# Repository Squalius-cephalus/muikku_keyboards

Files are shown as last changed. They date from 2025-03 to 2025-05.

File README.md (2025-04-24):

# Muikku58

Muikku58 is a RP2040 based 56-key column staggered split keyboard, that uses Redragon low profile switches. Design is inspired from REVIUNG41 and Corne keyboards.

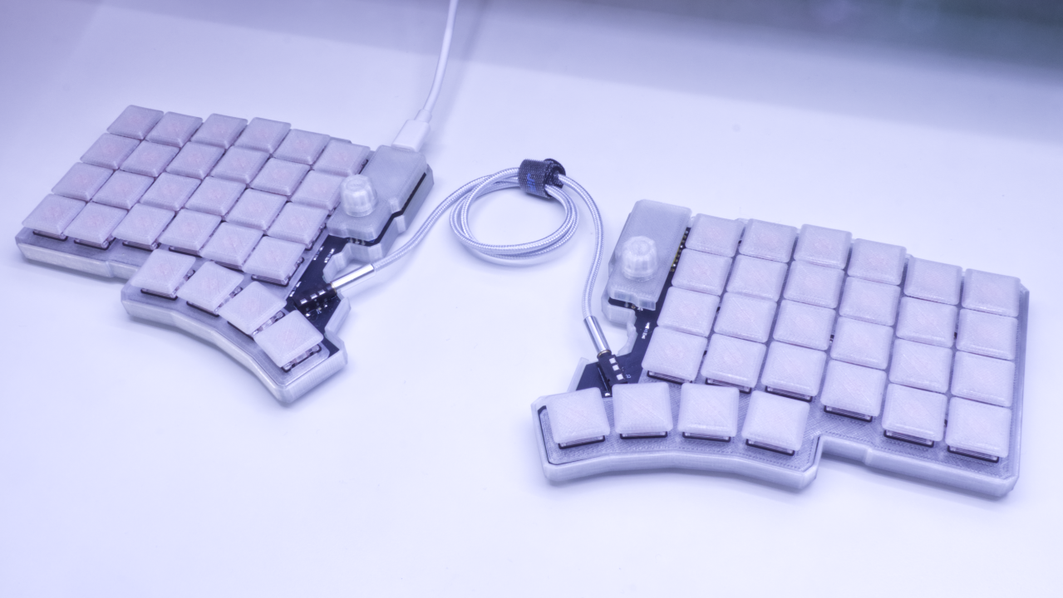
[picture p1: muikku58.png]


## Bill of materials

 - 2 x Muikku58 PCB
 - 2 x RP2040 Zero
 - 2 x 3D printed case
 - 2 x 3D printed plate
 - 2 x 3D printed MCU cover
 - 2 x EC11 Rotary encoders
 - 2  x TRRS connector(PJ320D)
 - 56 x Redragon low profile switches
 - 56 x Low profile MX compatible keycaps
 - 22 x M2 4mm bolt
 - 22 x M2 brass inserts(M2xL3xOD3.2)
 - 12 x Rubber feet

# Muikku18

Muikku18 is a 16-key macro pad, that also uses Redragon low profile switches. 

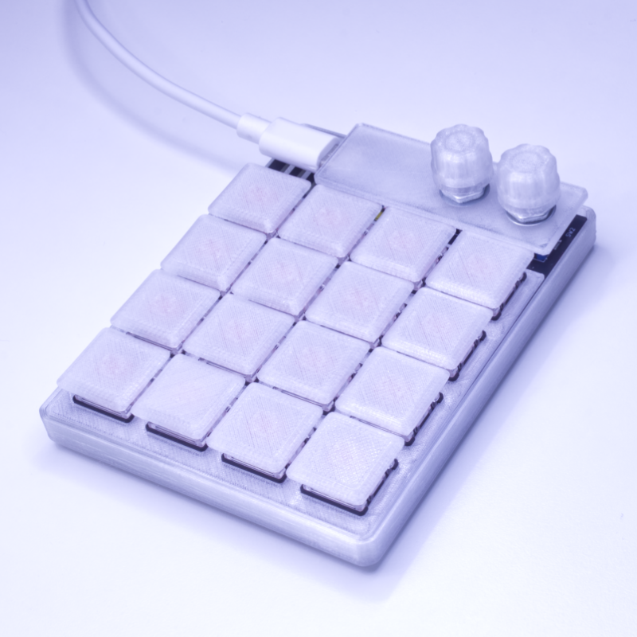
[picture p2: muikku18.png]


## Bill of materials

 - 1 x Muikku18 PCB
 - 1 x RP2040 Zero
 - 1 x 3D printed case
 - 1 x 3D printed plate
 - 1 x 3D printed MCU cover
 - 2 x EC11 Rotary encoders
 - 16 x Redragon low profile switches
 - 16 x Low profile MX compatible keycaps
 - 5 x M2 4mm bolt
 - 5 x M2 brass inserts(M2xL3xOD3.2)
 - 6 x Rubber feet

Both PCB design uses footprints from [ScottoKeebs](https://github.com/joe-scotto/scottokeebs/tree/main/Extras/ScottoKicad "ScottoKeebs") and [kbd library.](https://github.com/foostan/kbd "kbd library.")

Redragon switch footprint is from [keyboard-labs repository.](https://github.com/rgoulter/keyboard-labs "keyboard-labs")

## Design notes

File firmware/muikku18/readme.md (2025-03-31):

# Muikku18

Muikku18

Muikku18 is a RP2040 Zero based 18-key macro pad that uses Redragon low profile switches.

* Keyboard Maintainer: [Squalius-cephalus](https://github.com/Squalius-cephalus)
* Hardware Supported: Muikku58 PCB
* Hardware Availability: https://github.com/Squalius-cephalus/muikku_keyboards

Make example for this keyboard (after setting up your vial build environment):

    make muikku_keyboard/muikku58:vial

## Bootloader

Enter the bootloader in 2 ways:

* **Physical boot button**: Hold BOOT button down and connect MCU to the PC
* **Keycode in layout**: Press the key mapped to `QK_BOOT` if it is available

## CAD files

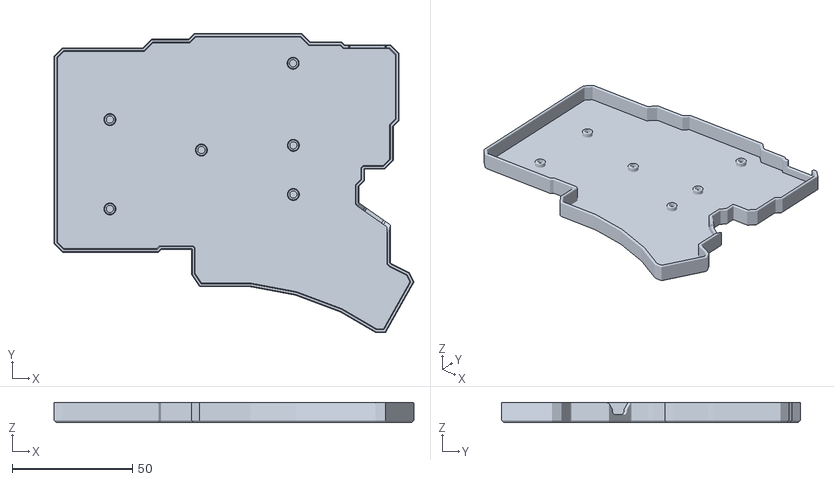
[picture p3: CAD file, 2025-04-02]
stl/muikku58_case.stl
149.5 x 124.3 x 8.50

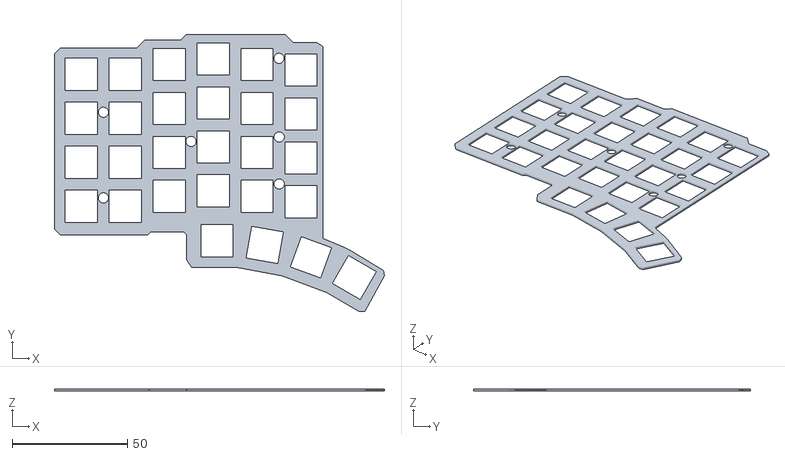
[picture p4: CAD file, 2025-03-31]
stl/muikku58_plate.stl
143.1 x 120.2 x 1.00

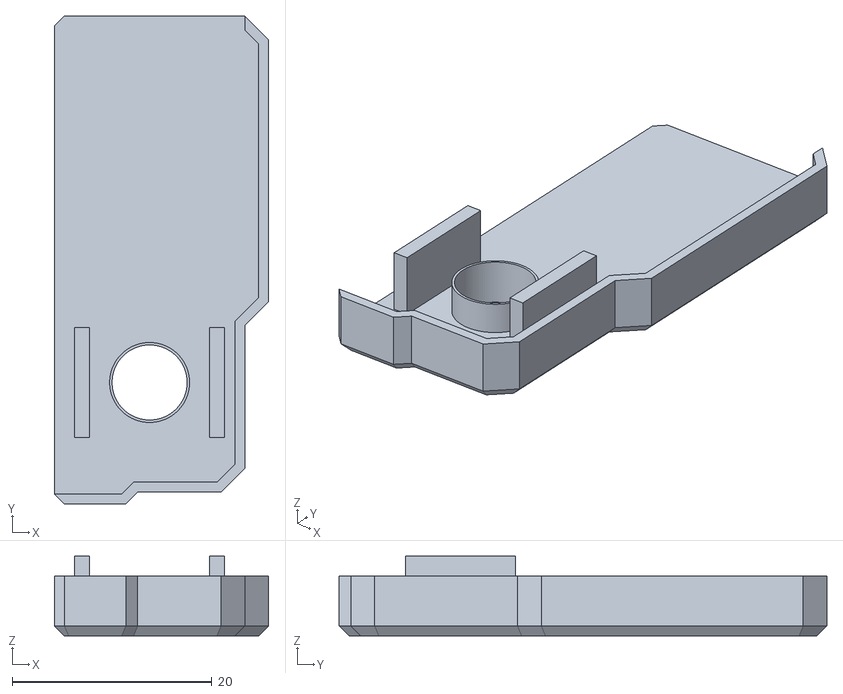
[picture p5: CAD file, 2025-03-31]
stl/muikku58_mcu_cover.stl
21.4 x 48.8 x 8.00

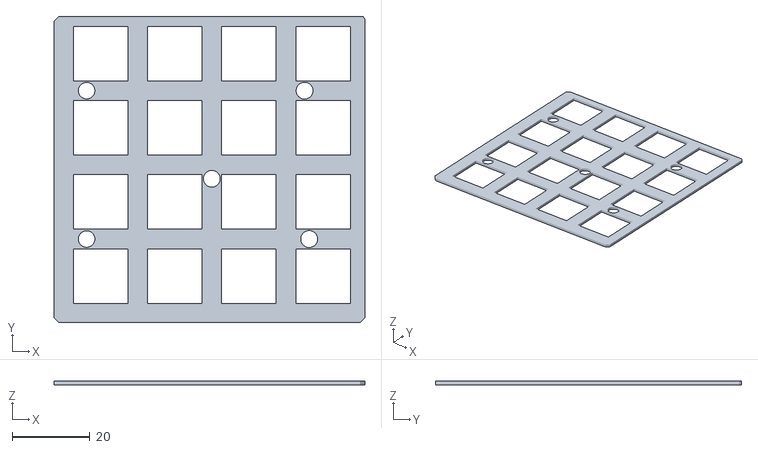
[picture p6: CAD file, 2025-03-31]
stl/muikku18_plate.stl
79.8 x 78.6 x 1

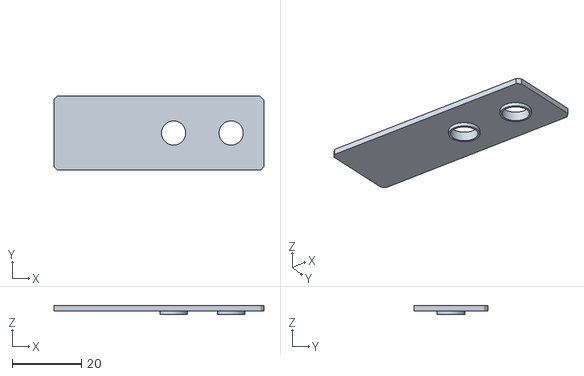
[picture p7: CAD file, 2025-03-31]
stl/muikku18_mcu_cover.stl
60.8 x 21.4 x 2.50

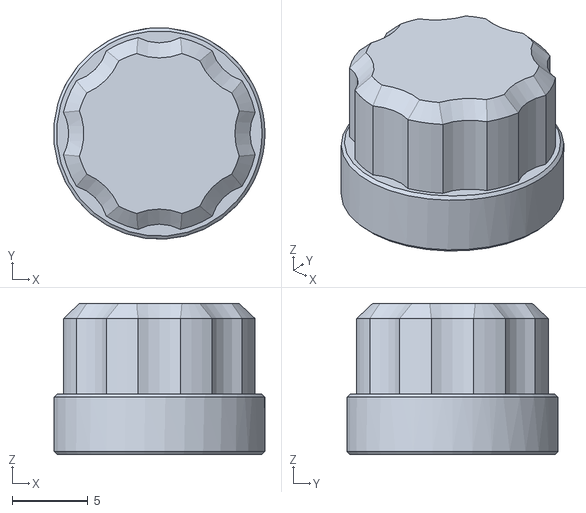
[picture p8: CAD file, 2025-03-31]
stl/knob.stl
14.0 x 14.0 x 10.0

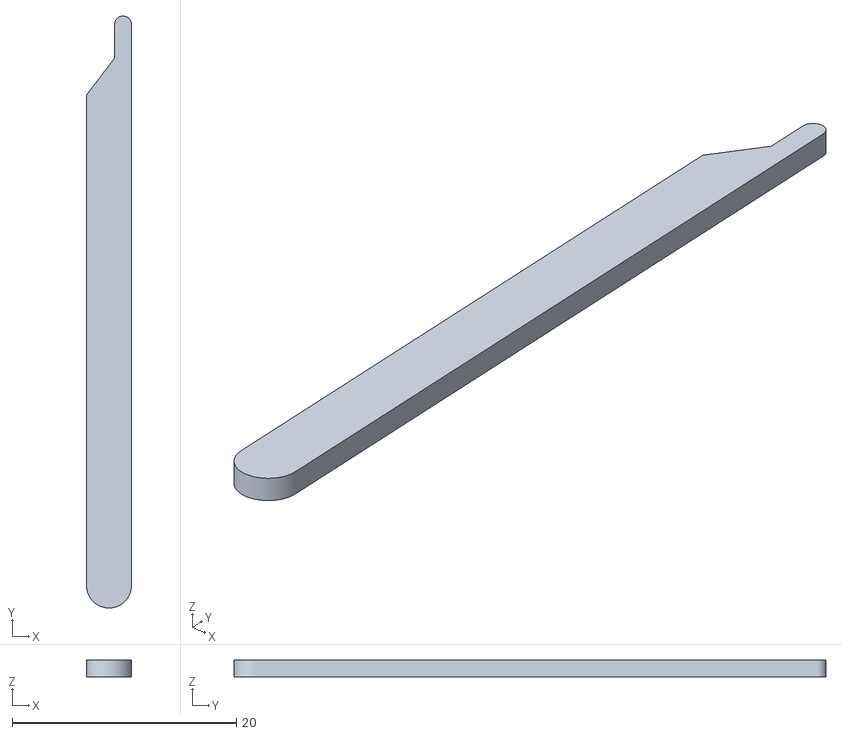
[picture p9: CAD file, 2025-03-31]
stl/mcu_tool.stl
4.00 x 52.8 x 1.50

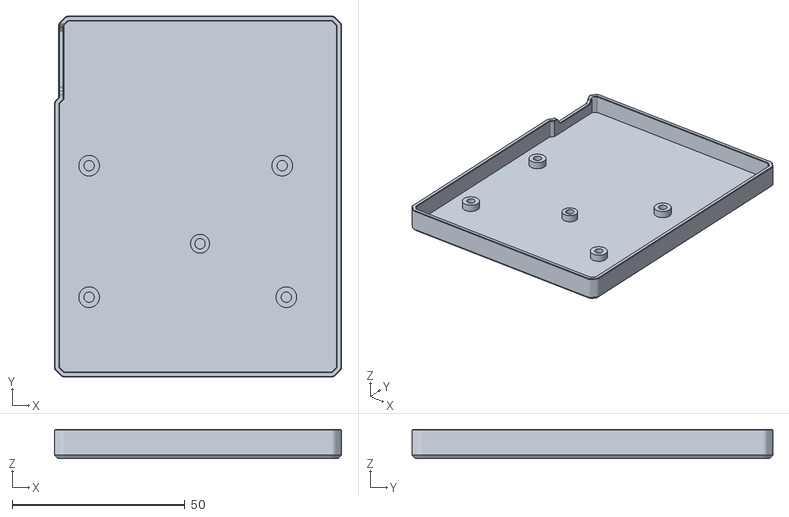
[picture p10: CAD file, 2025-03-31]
stl/muikku18_case.stl
83.2 x 104.6 x 8.50

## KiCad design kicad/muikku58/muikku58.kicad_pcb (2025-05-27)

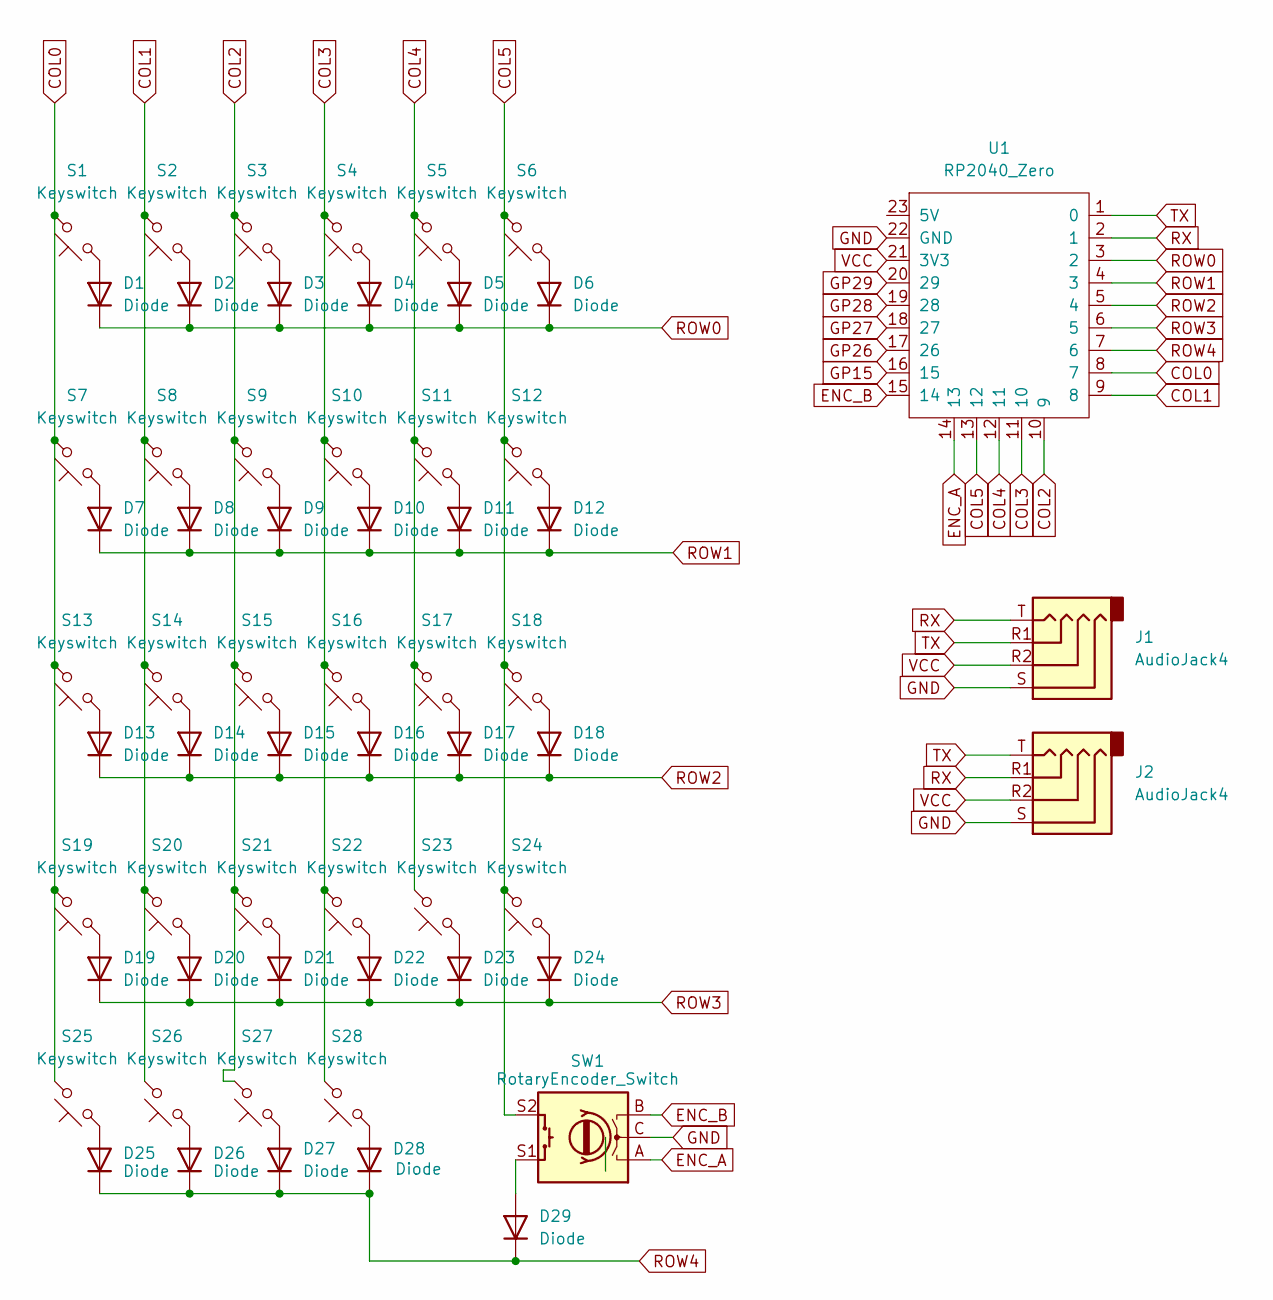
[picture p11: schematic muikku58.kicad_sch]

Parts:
D1, D2, D3, D4, D5, D6, D7, D8, D9, D10, D11, D12, D13, D14, D15, D16, D17, D18, D19, D20, D21, D22, D23, D24, D25, D26, D27, D28, D29: Diode; D3_TH_SMD_v2
J1, J2: AudioJack4; Jack_3.5mm_PJ320D_Horizontal
S1, S2, S3, S4, S5, S6, S7, S8, S9, S10, S11, S12, S13, S14, S15, S16, S17, S18, S19, S20, S21, S22, S23, S24, S25, S26, S27, S28: Keyswitch; SW_Redragon_LowProfile_PCB_1.00u_REV
SW1: RotaryEncoder_Switch; RotaryEncoder_Alps_EC11E-Switch_Vertical_H20mm
U1: RP2040_Zero

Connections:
COL0: S1.2, S7.2, S13.2, S19.2, S25.2, U1.8 (7)
COL1: S2.2, S8.2, S14.2, S20.2, S26.2, U1.9 (8)
COL2: S3.2, S9.2, S15.2, S21.2, S27.2, U1.10 (9)
COL3: S4.2, S10.2, S16.2, S22.2, S28.2, U1.11 (10)
COL4: S5.2, S11.2, S17.2, S23.2, U1.12 (11)
COL5: S6.2, S12.2, S18.2, S24.2, SW1.S2, U1.13 (12)
ENC_A: SW1.A, U1.14 (13)
ENC_B: SW1.B, U1.15 (14)
GND: J1.S, J2.S, SW1.C, U1.22 (GND)
GP15: U1.16 (15)
GP26: U1.17 (26)
GP27: U1.18 (27)
GP28: U1.19 (28)
GP29: U1.20 (29)
unnamed: D1.2 (A), S1.1
unnamed: D2.2 (A), S2.1
unnamed: D3.2 (A), S3.1
unnamed: D4.2 (A), S4.1
unnamed: D5.2 (A), S5.1
unnamed: D6.2 (A), S6.1
unnamed: D7.2 (A), S7.1
unnamed: D8.2 (A), S8.1
unnamed: D9.2 (A), S9.1
unnamed: D10.2 (A), S10.1
unnamed: D11.2 (A), S11.1
unnamed: D12.2 (A), S12.1
unnamed: D13.2 (A), S13.1
unnamed: D14.2 (A), S14.1
unnamed: D15.2 (A), S15.1
unnamed: D16.2 (A), S16.1
unnamed: D17.2 (A), S17.1
unnamed: D18.2 (A), S18.1
unnamed: D19.2 (A), S19.1
unnamed: D20.2 (A), S20.1
unnamed: D21.2 (A), S21.1
unnamed: D22.2 (A), S22.1
unnamed: D23.2 (A), S23.1
unnamed: D24.2 (A), S24.1
unnamed: D25.2 (A), S25.1
unnamed: D26.2 (A), S26.1
unnamed: D27.2 (A), S27.1
unnamed: D28.2 (A), S28.1
unnamed: D29.2 (A), SW1.S1
ROW0: D1.1 (K), D2.1 (K), D3.1 (K), D4.1 (K), D5.1 (K), D6.1 (K), U1.3 (2)
ROW1: D7.1 (K), D8.1 (K), D9.1 (K), D10.1 (K), D11.1 (K), D12.1 (K), U1.4 (3)
ROW2: D13.1 (K), D14.1 (K), D15.1 (K), D16.1 (K), D17.1 (K), D18.1 (K), U1.5 (4)
ROW3: D19.1 (K), D20.1 (K), D21.1 (K), D22.1 (K), D23.1 (K), D24.1 (K), U1.6 (5)
ROW4: D25.1 (K), D26.1 (K), D27.1 (K), D28.1 (K), D29.1 (K), U1.7 (6)
RX: J1.T, J2.R1, U1.2 (1)
TX: J1.R1, J2.T, U1.1 (0)
VCC: J1.R2, J2.R2, U1.21 (3V3)

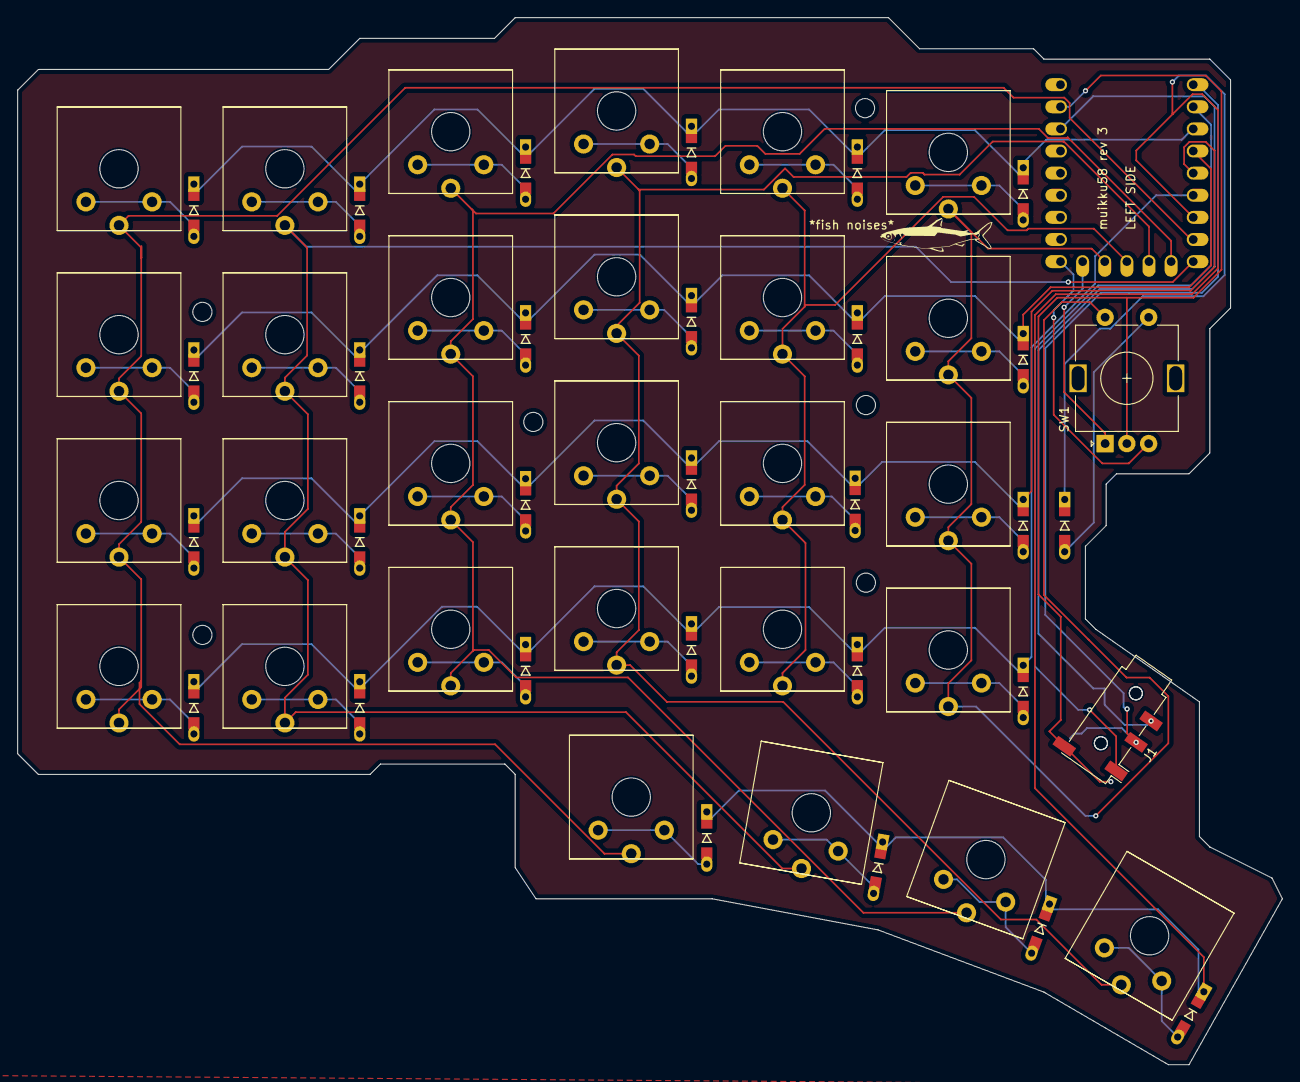
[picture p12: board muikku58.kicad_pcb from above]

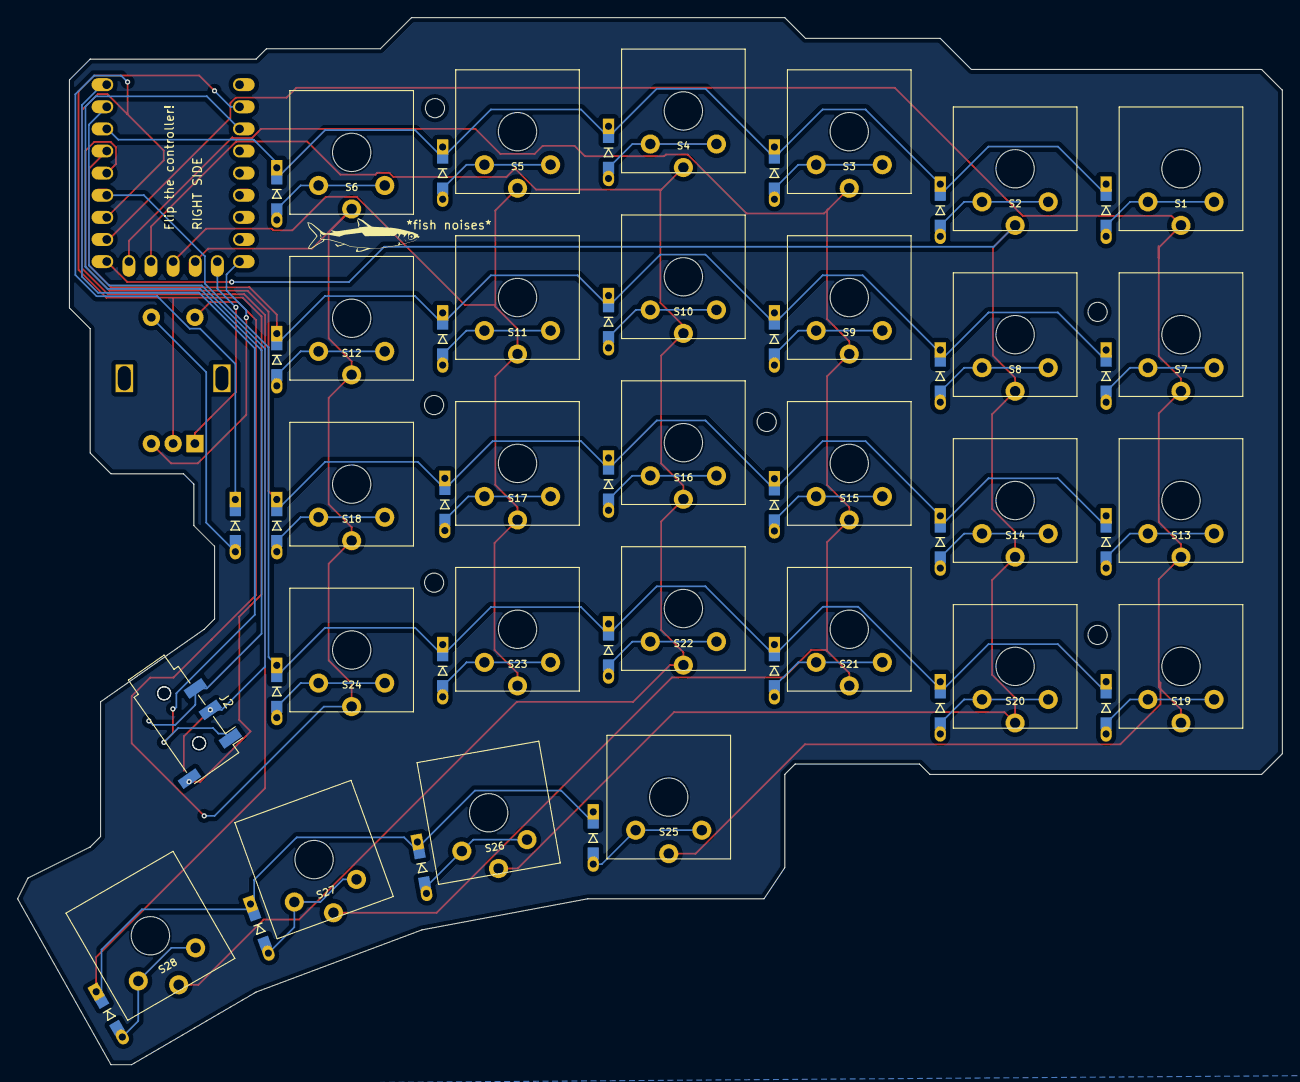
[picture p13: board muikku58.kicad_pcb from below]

Board: 2 copper layers, 145.3 x 120.3 mm, 61 parts (30 on the bottom side), 46 nets.

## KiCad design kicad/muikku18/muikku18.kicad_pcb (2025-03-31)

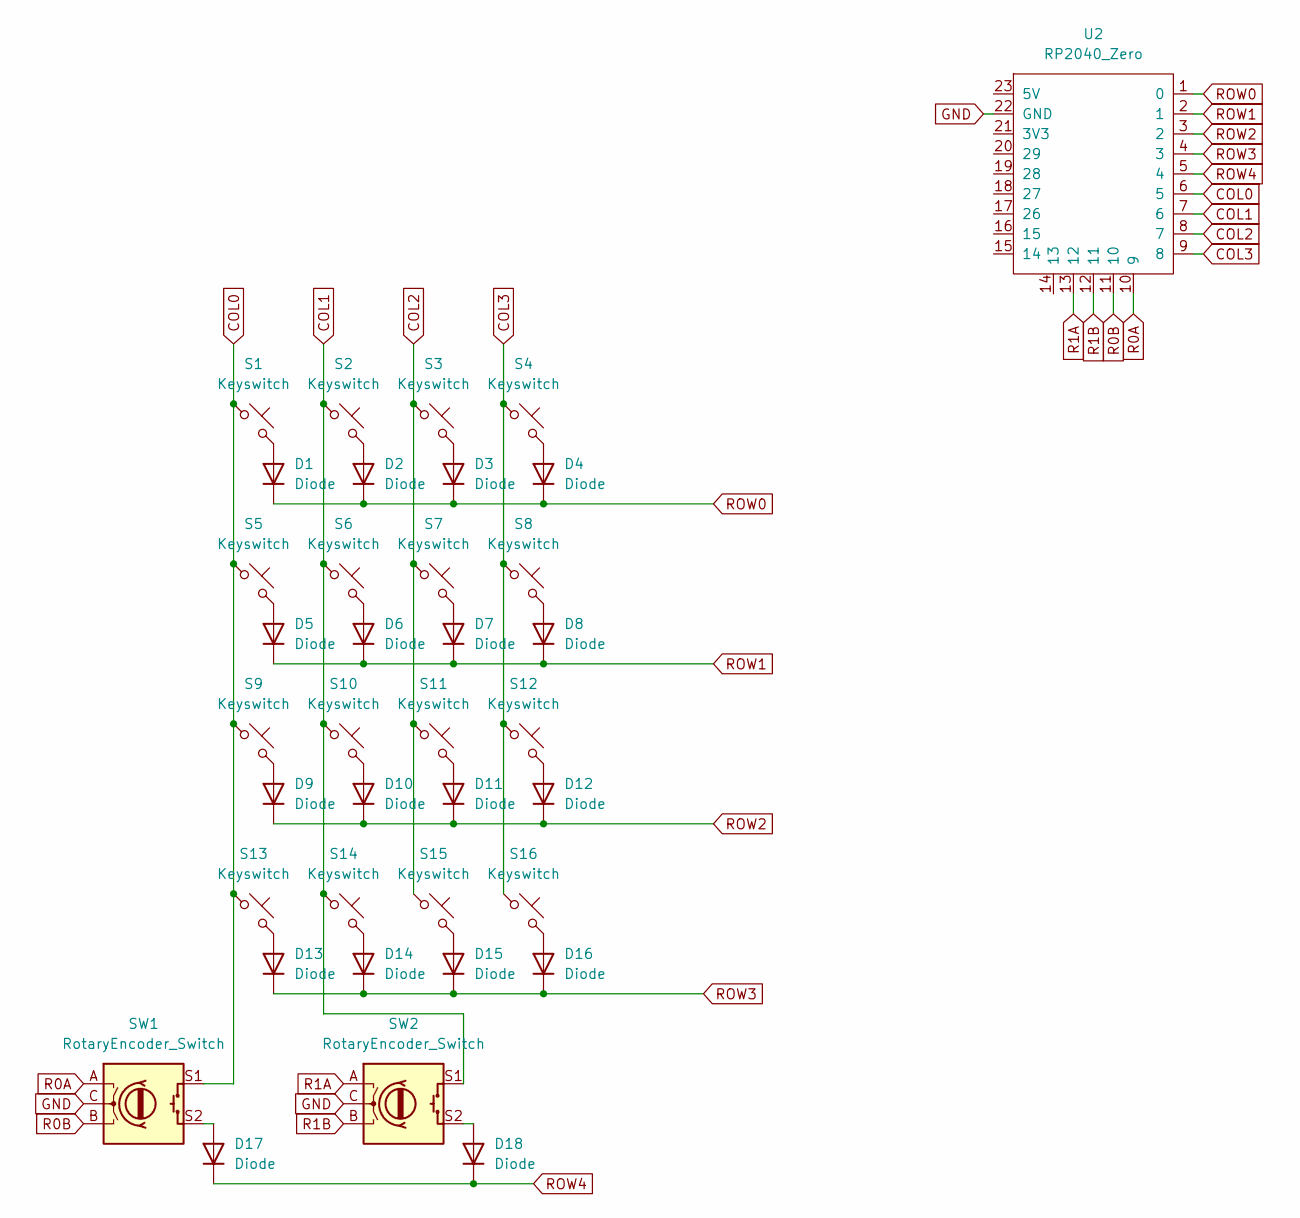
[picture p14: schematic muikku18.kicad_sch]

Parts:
D1, D2, D3, D4, D5, D6, D7, D8, D9, D10, D11, D12, D13, D14, D15, D16, D17, D18: Diode; D3_TH_SMD_v2
S1, S2, S3, S4, S5, S6, S7, S8, S9, S10, S11, S12, S13, S14, S15, S16: Keyswitch; SW_Redragon_LowProfile_PCB_1.00u
SW1, SW2: RotaryEncoder_Switch; RotaryEncoder_Alps_EC11E-Switch_Vertical_H20mm
U2: RP2040_Zero

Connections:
COL0: S1.1, S5.1, S9.1, S13.1, SW1.S1, U2.6 (5)
COL1: S2.1, S6.1, S10.1, S14.1, SW2.S1, U2.7 (6)
COL2: S3.1, S7.1, S11.1, S15.1, U2.8 (7)
COL3: S4.1, S8.1, S12.1, S16.1, U2.9 (8)
GND: SW1.C, SW2.C, U2.22 (GND)
unnamed: D1.2 (A), S1.2
unnamed: D2.2 (A), S2.2
unnamed: D3.2 (A), S3.2
unnamed: D4.2 (A), S4.2
unnamed: D5.2 (A), S5.2
unnamed: D6.2 (A), S6.2
unnamed: D7.2 (A), S7.2
unnamed: D8.2 (A), S8.2
unnamed: D9.2 (A), S9.2
unnamed: D10.2 (A), S10.2
unnamed: D11.2 (A), S11.2
unnamed: D12.2 (A), S12.2
unnamed: D13.2 (A), S13.2
unnamed: D14.2 (A), S14.2
unnamed: D15.2 (A), S15.2
unnamed: D16.2 (A), S16.2
unnamed: D17.2 (A), SW1.S2
unnamed: D18.2 (A), SW2.S2
R0A: SW1.A, U2.10 (9)
R0B: SW1.B, U2.11 (10)
R1A: SW2.A, U2.13 (12)
R1B: SW2.B, U2.12 (11)
ROW0: D1.1 (K), D2.1 (K), D3.1 (K), D4.1 (K), U2.1 (0)
ROW1: D5.1 (K), D6.1 (K), D7.1 (K), D8.1 (K), U2.2 (1)
ROW2: D9.1 (K), D10.1 (K), D11.1 (K), D12.1 (K), U2.3 (2)
ROW3: D13.1 (K), D14.1 (K), D15.1 (K), D16.1 (K), U2.4 (3)
ROW4: D17.1 (K), D18.1 (K), U2.5 (4)

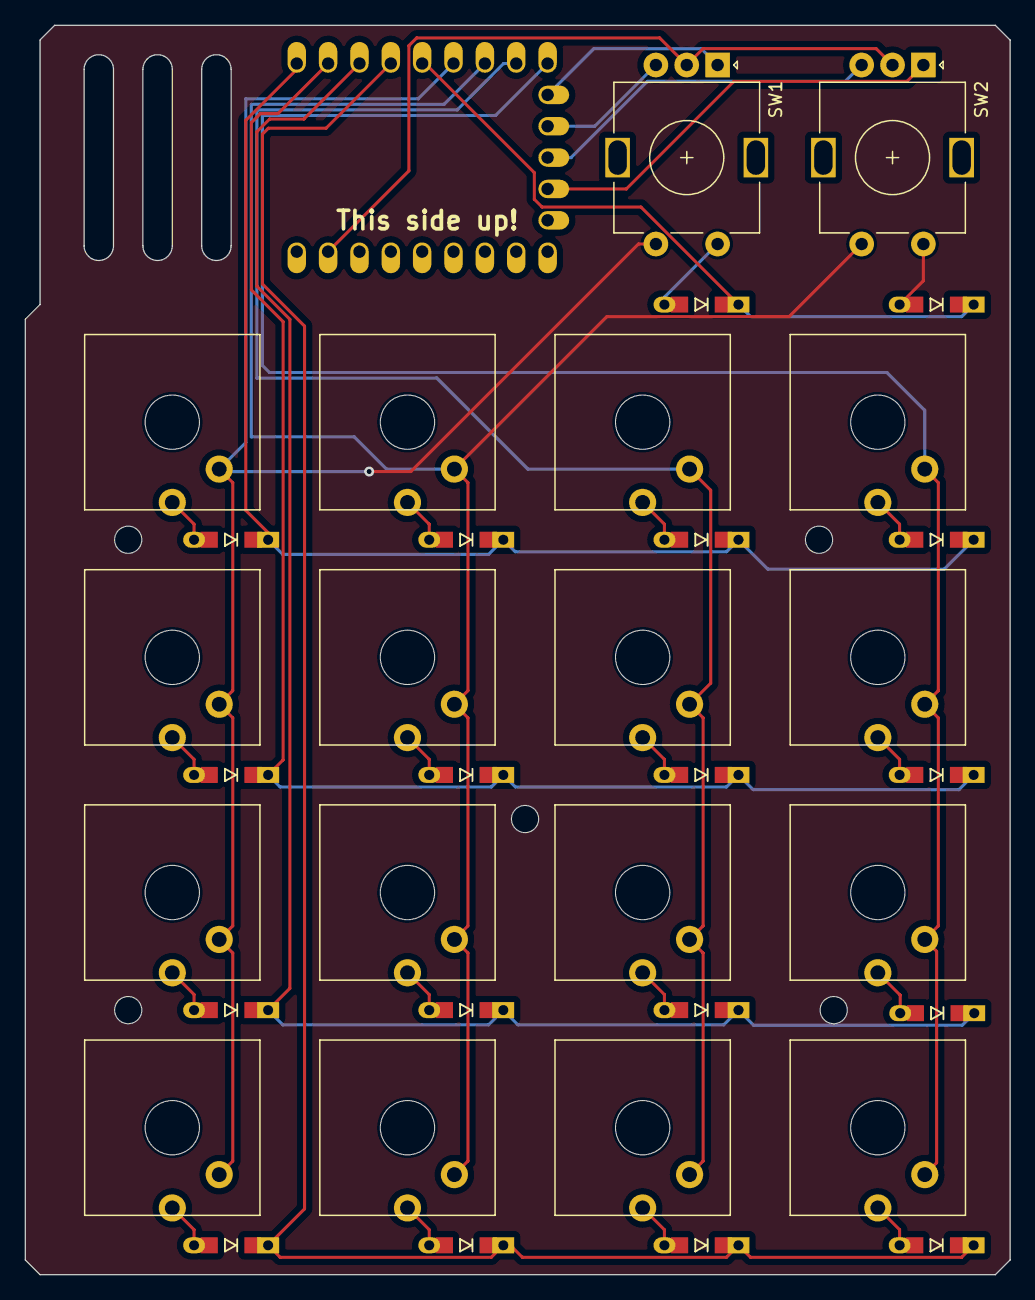
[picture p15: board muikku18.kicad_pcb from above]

Board: 2 copper layers, 79.8 x 101.2 mm, 37 parts (0 on the bottom side), 32 nets.

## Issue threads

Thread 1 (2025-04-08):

PCB top plate?

pranciskus, 2025-04-08:
Can we use a PCB for the top button plate? Enough clearance? Additional Gerber files for easy ordering would be wonderful.

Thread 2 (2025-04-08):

Boot button PCB hole

pranciskus, 2025-04-08:
Can we make a small hole in the PCB for more convenient BOOT button access with, e.g., a toothpick?

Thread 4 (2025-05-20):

Rotary encoder track interrupted

alextervoort, 2025-05-20:
One of the mounting holes for J1 is going straight through the track of the rotary encoder switch.

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

alextervoort, 2025-05-22:
Traced the track to the MCU pin and there is an easy way to resolve is you have this version of the PCB.
Turns out the MCU pin is directly opposite the switch pin, just solder a bridge like this;

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

Squalius-cephalus, 2025-05-27:
Thanks for the comment, I fixed the trace!

Closed 2025-05-27.

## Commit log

2025-04-02 Added case STL and fixed the both keyboards UID
    [muikku58_case.stl]
2025-04-07 Fixed the encoder mapping
2025-05-27 Fixed trace near the TRRS connector
    [muikku58.kicad_pcb]
